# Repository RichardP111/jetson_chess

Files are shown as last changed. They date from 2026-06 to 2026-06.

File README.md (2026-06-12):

# ♟️ Jetson Smart Chess Board

<p align="center">
  <strong>AI-powered smart chess board running entirely on a Jetson Orin Nano</strong>
</p>

<p align="center">
  
  
  
  
</p>

---

## 🚀 Overview

A fully self-contained smart chess board powered by the **NVIDIA Jetson Orin Nano**.

- ♟️ Three game modes: AI (Stockfish), Online (Lichess), Local 2-Player
- 🎯 Pawn promotion selector (Q R B N) via coloured LED quadrants
- ↩️ Undo last move (button combo or web dashboard)
- 📊 Eval bar on OLED and web dashboard
- 🔊 Voice announcements — auto-enabled when a USB speaker is connected
- 💾 USB game save — auto-saves PGN if a USB drive is plugged in
- 🧠 Post-game blunder analysis (top-3 mistakes highlighted)
- 🌐 Web dashboard with move input, custom LED theme builder, PGN download, OTA update
- ⚡ Fast startup (~1 second instead of 64)
- 🧩 Central `config.py` — no more scattered magic numbers

---

## ✨ Features

### Game Modes
| Button | Mode | Description |
|---|---|---|
| 1 | vs AI | Stockfish on-device, configurable difficulty 1-20 |
| 2 | Online | Lichess board API (requires token) |
| 3 | Local 2P | Pass-and-play, no network needed |

### Controls
| Action | Input |
|---|---|
| Hint | Press HINT button |
| Undo last move | Hold Btn 8 + press HINT |
| New game | Hold OK + press HINT |
| Promotion choice | Buttons 1-4 when pawn reaches back rank |

### Visual Feedback
| Event | LED |
|---|-----|
| Move | Fading trail animation |
| Hint | Cyan trail + squares |
| Capture | Red flash × 3 |
| Check | Red pulse from king |
| Promotion Q | White flash |
| Promotion R | Red flash |
| Promotion B | Blue flash |
| Promotion N | Yellow flash |
| Undo | Orange right-to-left wipe |
| Checkmate | Rainbow victory sweep |

---

## 🔧 Hardware

| Component | Description |
|---|---|
| Jetson Orin Nano 8GB | Main compute platform |
| WS2812B LEDs (64 + 22) | Chessboard + control panel |
| Push buttons (×10) | Input system |
| TXS0108E | Logic level shifter |
| SSD1306 OLED (128×64) | Status display |
| USB speaker (optional) | Voice announcements |
| USB drive (optional) | Game save as PGN |

### GPIO Mapping (Jetson 40-pin Header)
| Function | Pin |
|---|-----|
| Chessboard LED Data | 32 |
| Control Panel LED Data | 33 |
| Buttons 1-9 | 7, 11, 13, 15, 29, 31, 26, 24, 19 |
| HINT button | 16 |

---

## 🖥️ Software Setup

### 1. Install system packages
```bash
sudo apt update
sudo apt install python3-pip stockfish espeak-ng -y
```

### 2. Install Python packages
```bash
pip install -r requirements.txt --break-system-packages
```

### 3. Setup GPIO permissions
```bash
sudo groupadd -f gpio
sudo usermod -aG gpio $USER
sudo cp /opt/nvidia/jetson-gpio/etc/99-gpio.rules /etc/udev/rules.d/
sudo udevadm control --reload-rules && sudo udevadm trigger
```

### 4. LED permissions
```bash
sudo cp scripts/99-ws281x.rules /etc/udev/rules.d/
sudo udevadm control --reload-rules
```

### 5. Configure .env
```bash
cp .env.example .env
# Edit .env and fill in FLASK_SECRET_KEY (required)
# Add LICHESS_TOKEN if using online play
# Add OTA_TOKEN to enable web dashboard updates
```

Generate a secret key:
```bash
python3 -c "import secrets; print(secrets.token_hex(32))"
```

---

## ▶️ Running

### Development (no hardware)
```bash
MOCK_LEDS=1 MOCK_BUTTONS=1 MOCK_OLED=1 MOCK_VOICE=1 MOCK_ONLINE=1 \
  python3 -m pytest tests/test_mock_game.py -v
```

### Hardware test
```bash
sudo python3 tests/test_leds_buttons.py
```

### Stockfish test
```bash
python3 tests/test_stockfish.py
```

### Full system
```bash
sudo python3 main.py
```

### Auto-start on boot
```bash
sudo cp scripts/chess.service /etc/systemd/system/
sudo systemctl daemon-reload
sudo systemctl enable chess.service
sudo systemctl start chess.service
```

---

## 🌐 Web Dashboard

Access at `http://<jetson-ip>:5000` from any device on the same network.

Features:
- Live board with move arrows and eval bar
- Enter moves directly from browser (UCI notation, e.g. `e2e4`)
- Request hints and undo
- New game
- LED theme selector + custom colour picker
- Save game to USB / download PGN
- Voice toggle
- Jetson system stats (CPU temp, load, RAM)
- OTA git-pull + restart (requires `OTA_TOKEN` in `.env`)

---

## 🔊 Voice Announcements

Voice is automatically enabled when a USB speaker is detected. No configuration needed — just plug one in. If no speaker is present, the feature is silently disabled.

Install the TTS engine (if not already via apt):
```bash
sudo apt install espeak-ng -y
# OR
pip install pyttsx3 --break-system-packages
```

To permanently disable voice even with a speaker: set `DISABLE_VOICE=1` in `.env`.

---

## 💾 USB Game Save

If a USB drive is plugged in, games are automatically saved as PGN files after each game ends. Files are stored in a `chess_games/` folder on the drive. You can also trigger a manual save via the web dashboard.

No USB drive? No problem — the feature is silently skipped.

---

## 📁 Project Structure

```
jetson_chess/
├── main.py              
├── config.py            
├── voice.py             
├── usb_storage.py       
├── hardware/
│   ├── leds.py
│   └── buttons.py
├── chess_engine/
│   ├── board_state.py
│   └── stockfish.py
├── online/
│   └── lichess.py
├── ui/
│   ├── display.py
│   └── animations.py
├── oled/
│   └── oled_display.py
├── web/
│   └── server.py
├── tests/
│   ├── test_mock_game.py
│   ├── test_leds_buttons.py
│   └── test_stockfish.py
└── scripts/
    ├── chess.service
    └── 99-ws281x.rules
```

---

## ⚖️ License & Acknowledgements

- **Software:** MIT License
- **Hardware (3D models):** CC BY-NC-SA 4.0

Hardware models are a derivative of the original Smart Chess project by DIYMachines (CC BY-NC-SA 4.0). Modifications: Jetson electronics bay, airflow cutouts for Jetson fan, repositioned OLED mount, updated button panel layout.

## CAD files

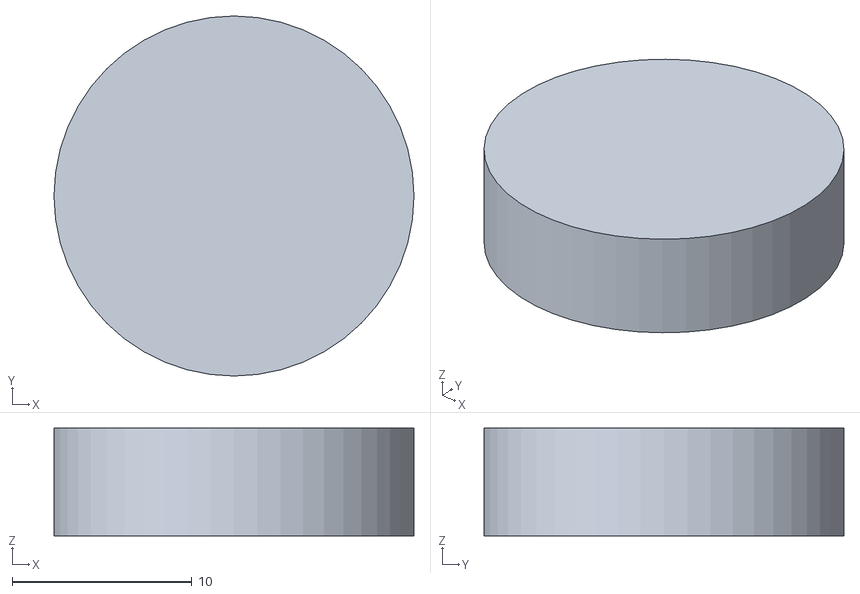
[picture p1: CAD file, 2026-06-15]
3D models/Base/Chessboard - Feet.stl
20.0 x 20.0 x 6.00

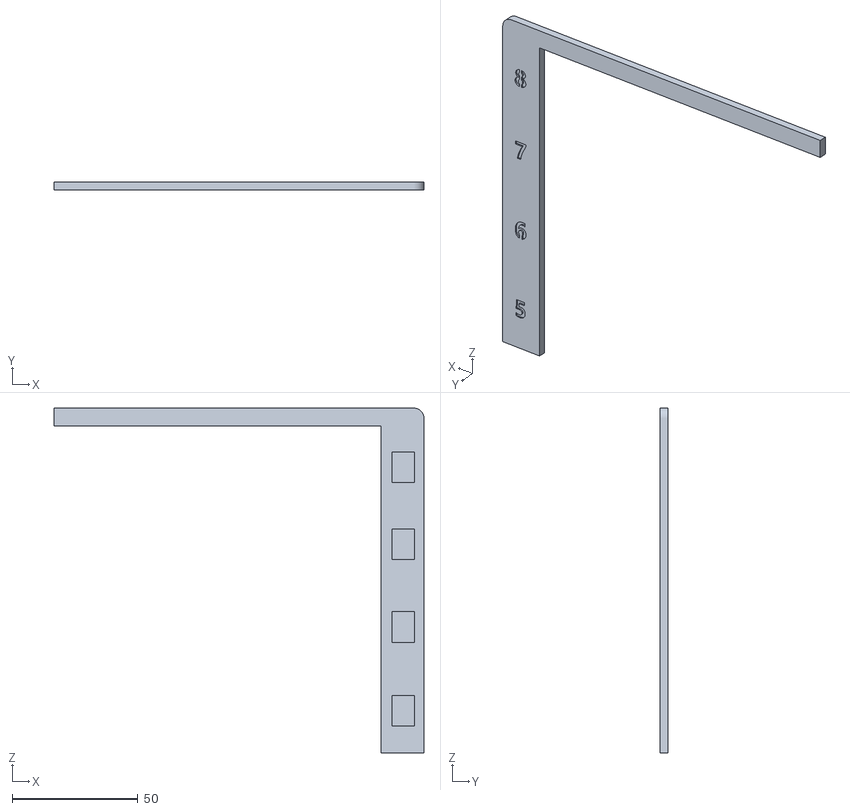
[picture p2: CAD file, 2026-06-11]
3D models/Labels/Chessboard - Label 1-4.STL
147.0 x 3.00 x 136.9

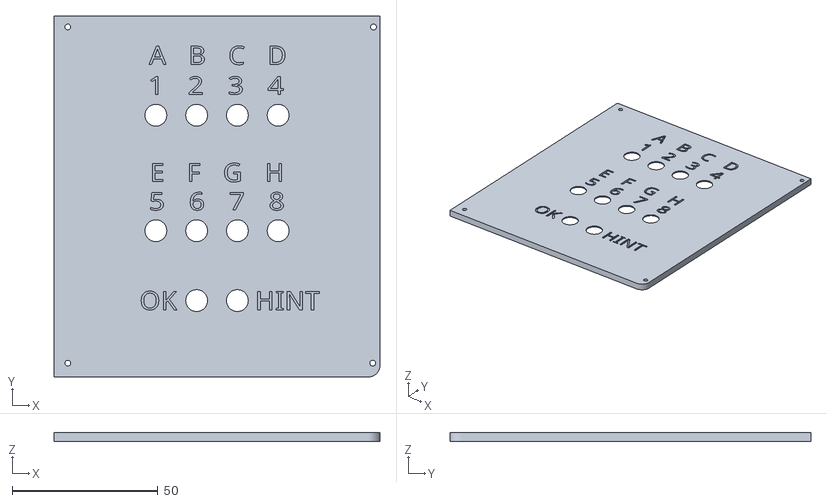
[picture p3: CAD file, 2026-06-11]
3D models/Panels/Chessboard - Button Panel.stl
112.0 x 124.0 x 3.00

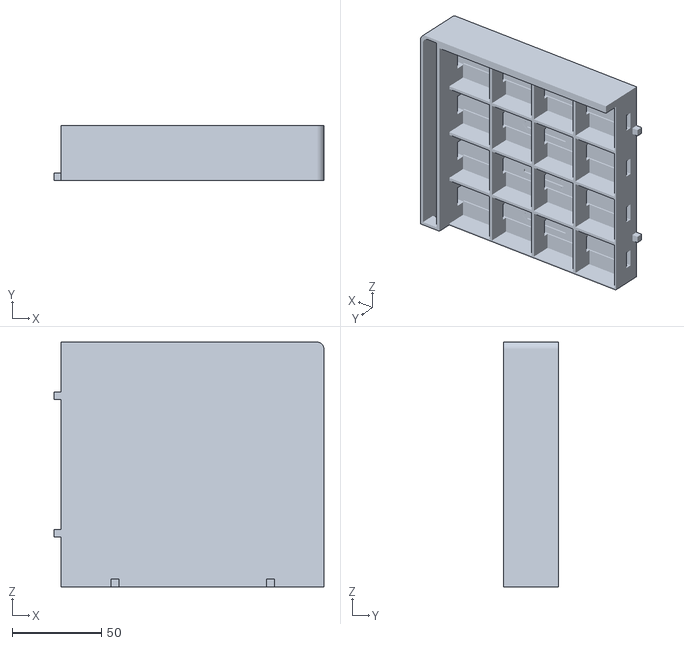
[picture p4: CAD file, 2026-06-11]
3D models/Base/Chessboard - Top Lights.STL
151.0 x 31.0 x 136.9

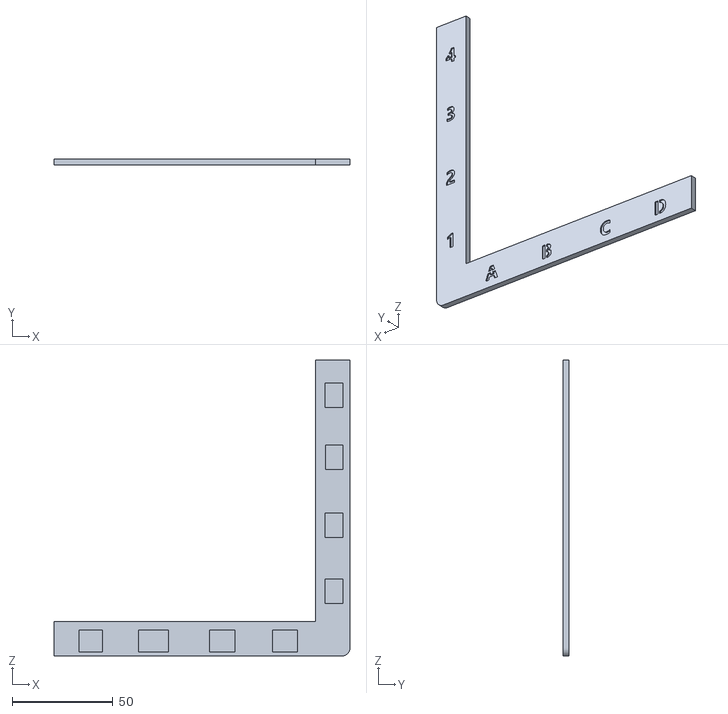
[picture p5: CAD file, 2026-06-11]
3D models/Labels/Chessboard - Label A1-D4.STL
147.0 x 3.00 x 147.0

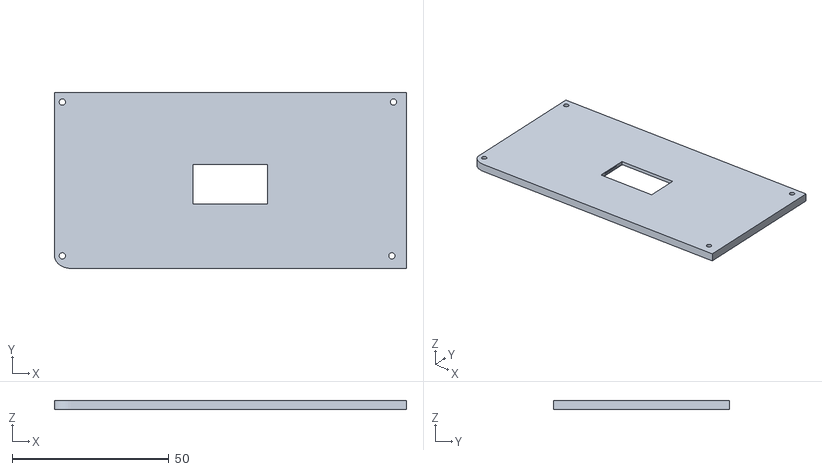
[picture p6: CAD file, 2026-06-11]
3D models/Panels/Chessboard - Screen Panel.stl
112.1 x 56.0 x 3.00

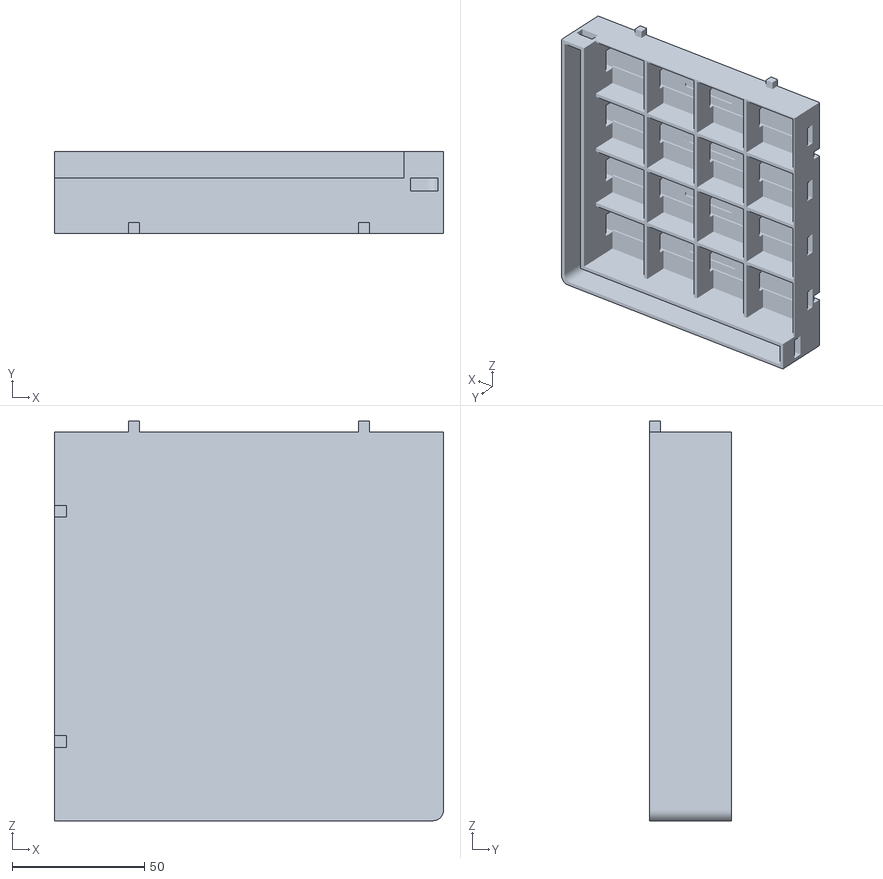
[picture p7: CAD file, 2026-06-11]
3D models/Base/Chessboard - Bottom Lights.STL
147.0 x 31.0 x 150.9

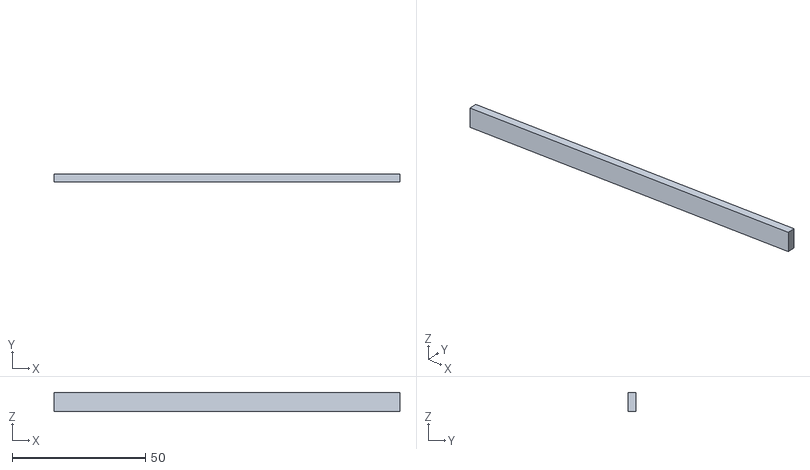
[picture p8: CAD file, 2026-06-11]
3D models/Labels/Chessboard - Blank.STL
129.8 x 3.00 x 7.15

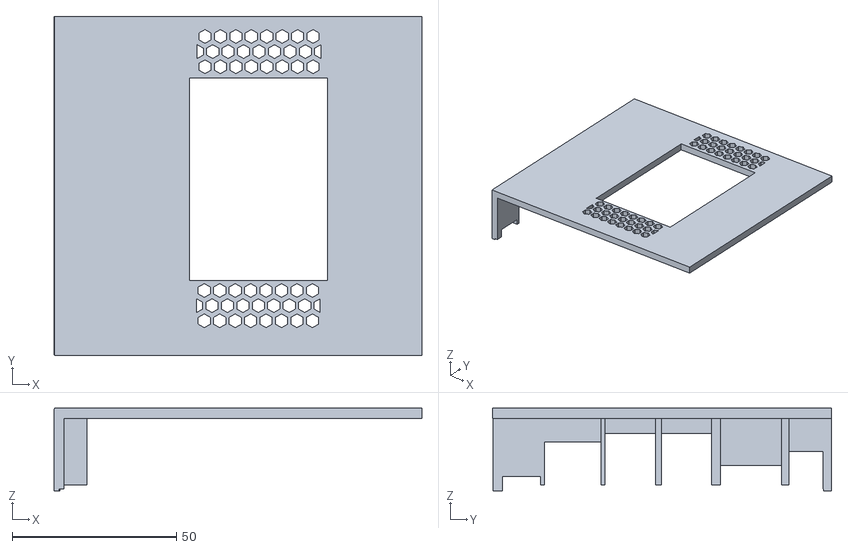
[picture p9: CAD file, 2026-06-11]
3D models/Panels/Chessboard - Middle Jetson Panel.stl
112.0 x 103.2 x 25.2

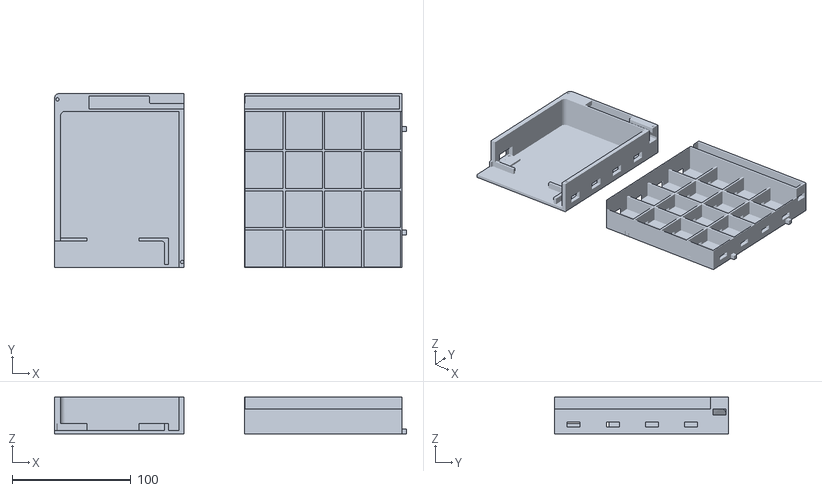
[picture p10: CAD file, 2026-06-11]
3D models/Base/Chessboard - Bottom Elec Split.stl
296.6 x 146.6 x 31.0

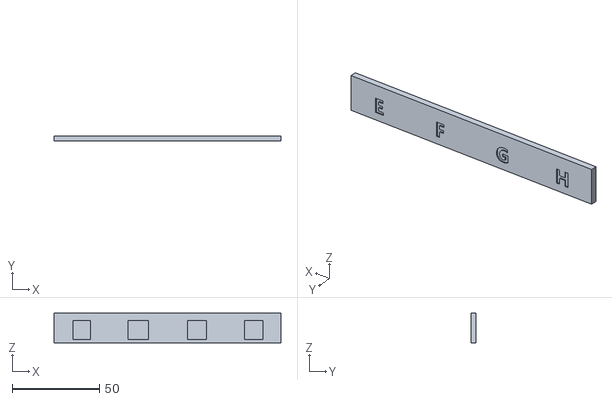
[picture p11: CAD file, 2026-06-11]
3D models/Labels/Chessboard - Label 5-8.STL.STL
129.8 x 3.00 x 17.0

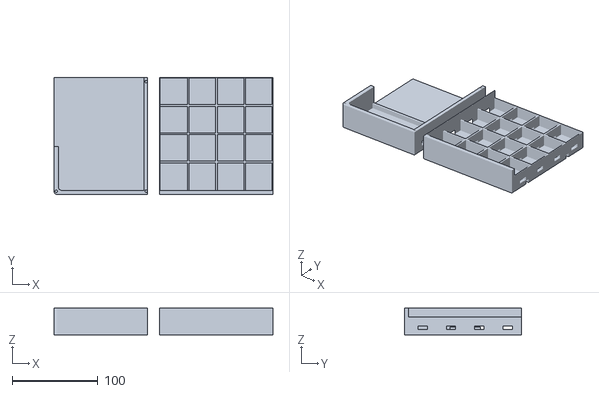
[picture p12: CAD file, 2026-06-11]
3D models/Base/Chessboard - Top Elec Split.stl
255.7 x 136.9 x 31.0

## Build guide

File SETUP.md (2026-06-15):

# Jetson Smart Chess Board — Full Setup Guide

Run these commands **in order** on the Jetson Orin Nano (JetPack 6).
Everything assumes you are in the project root: `cd ~/jetson_chess`

---

## 1. System packages

```bash
sudo apt update && sudo apt upgrade -y

sudo apt install -y \
    python3-pip \
    stockfish \
    espeak-ng \
    ntfs-3g \
    exfatprogs \
    i2c-tools \
    git
```

> **exFAT note:** if `exfatprogs` isn't found try `exfat-fuse` instead.

---

## 2. Python packages

```bash
pip install -r requirements.txt --break-system-packages
```

If `rpi_ws281x` fails (it's Raspberry Pi only — the Jetson uses SPI directly
via `spidev`):

```bash
pip install -r requirements.txt --break-system-packages --ignore-requires-python
# or just skip rpi_ws281x — it's not used at runtime, only spidev is
pip install spidev --break-system-packages
```

---

## 3. Environment file

```bash
cp .env.example .env   # or create it fresh:
nano .env
```

Minimum required:

```
FLASK_SECRET_KEY=<generate one — see below>
LICHESS_TOKEN=        # optional, only needed for online mode
OTA_TOKEN=            # optional, enables web dashboard git-pull updates
DISABLE_VOICE=0       # set to 1 to always silence TTS
```

Generate a secret key:

```bash
python3 -c "import secrets; print(secrets.token_hex(32))"
```

---

## 4. GPIO permissions

```bash
sudo groupadd -f gpio
sudo usermod -aG gpio $USER

# Jetson GPIO udev rule (comes with JetPack, just link it)
sudo cp /opt/nvidia/jetson-gpio/etc/99-gpio.rules /etc/udev/rules.d/ 2>/dev/null || true
sudo udevadm control --reload-rules && sudo udevadm trigger
```

---

## 5. LED (SPI) permissions

```bash
sudo cp scripts/99-ws281x.rules /etc/udev/rules.d/
sudo udevadm control --reload-rules && sudo udevadm trigger
```

The chess LEDs use SPI1 MOSI (BOARD pin 19) via `/dev/spidev0.0`.
Make sure SPI is enabled in the Jetson pin-mux / `jetson-io` tool if it
isn't already.

---

## 6. USB hotplug (plug-and-play USB drives)

```bash
# Mount script
sudo cp scripts/chess-usb-mount.sh /usr/local/bin/
sudo chmod +x /usr/local/bin/chess-usb-mount.sh

# udev rule
sudo cp scripts/99-chess-usb.rules /etc/udev/rules.d/
sudo udevadm control --reload-rules && sudo udevadm trigger

# Fixed mount point
sudo mkdir -p /mnt/usb
```

After this, plugging in any FAT32/exFAT/NTFS USB drive will auto-mount
it at `/mnt/usb` within about a second. Unplugging safely unmounts it.

Check the mount log any time:

```bash
cat /tmp/chess-usb.log
```

---

## 7. OLED I2C

The SSD1306 OLED uses I2C bus 7 (BOARD pins 3/5) by default.
Confirm it's visible:

```bash
sudo i2cdetect -y 7
# Should show 3c at address 0x3C
```

If it's on a different bus, set in `.env`:

```
OLED_I2C_PORT=1
OLED_I2C_ADDR=0x3C
```

---

## 8. Auto-start on boot (systemd)

```bash
sudo cp scripts/chess.service /etc/systemd/system/
sudo systemctl daemon-reload
sudo systemctl enable chess.service
sudo systemctl start chess.service
```

Check it's running:

```bash
sudo systemctl status chess.service
sudo journalctl -u chess.service -f   # live logs
```

---

## 9. Test everything works

```bash
# Test Stockfish
python3 tests/test_stockfish.py

# Test LEDs + buttons (needs physical hardware)
sudo python3 tests/test_leds_buttons.py

# Full mock run (no hardware needed — keyboard simulates buttons)
MOCK_LEDS=1 MOCK_BUTTONS=1 MOCK_OLED=1 MOCK_VOICE=1 MOCK_ONLINE=1 \
    python3 main.py
```

---

## 10. Web dashboard

Once running, open a browser on any device on the same network:

```
http://<jetson-ip>:5000
```

Find the Jetson's IP:

```bash
hostname -I
```

Or it shows on the OLED at startup.

---

## All-in-one first-time setup (copy/paste)

```bash
# Run from the project root as your normal user
set -e

# 1. System packages
sudo apt update
sudo apt install -y python3-pip stockfish espeak-ng ntfs-3g exfatprogs i2c-tools git

# 2. Python packages
pip install -r requirements.txt --break-system-packages

# 3. .env
if [ ! -f .env ]; then
    echo "FLASK_SECRET_KEY=$(python3 -c 'import secrets; print(secrets.token_hex(32))')" > .env
    echo "LICHESS_TOKEN=" >> .env
    echo "OTA_TOKEN=" >> .env
    echo "DISABLE_VOICE=0" >> .env
    echo "Created .env — edit it to add LICHESS_TOKEN if you want online play"
fi

# 4. GPIO
sudo groupadd -f gpio
sudo usermod -aG gpio $USER
sudo cp /opt/nvidia/jetson-gpio/etc/99-gpio.rules /etc/udev/rules.d/ 2>/dev/null || true

# 5. LEDs
sudo cp scripts/99-ws281x.rules /etc/udev/rules.d/

# 6. USB hotplug
sudo cp scripts/chess-usb-mount.sh /usr/local/bin/
sudo chmod +x /usr/local/bin/chess-usb-mount.sh
sudo cp scripts/99-chess-usb.rules /etc/udev/rules.d/
sudo mkdir -p /mnt/usb

# Reload udev
sudo udevadm control --reload-rules && sudo udevadm trigger

# 7. Systemd service
sudo cp scripts/chess.service /etc/systemd/system/
sudo systemctl daemon-reload
sudo systemctl enable chess.service

echo ""
echo "✅ Setup complete. Start with:"
echo "   sudo systemctl start chess.service"
echo "   sudo journalctl -u chess.service -f"
```

---

## Troubleshooting

| Problem | Check |
|---|---|
| LEDs not working | `ls /dev/spidev*` — SPI must be enabled in jetson-io |
| OLED blank | `sudo i2cdetect -y 7` — confirm address 0x3C |
| Buttons not responding | `groups` — must include `gpio`; log out and back in |
| USB not detected | `cat /tmp/chess-usb.log` — check mount script output |
| Web dashboard won't load | `sudo journalctl -u chess.service -f` — check for port 5000 errors |
| Lichess not connecting | Check `LICHESS_TOKEN` in `.env` is a valid board token |
| Voice silent | `aplay -l` — confirm USB speaker shows as a card |

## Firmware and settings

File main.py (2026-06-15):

#!/usr/bin/env python3
# =============================================================================
# main.py
# Author : Richard Pu
# Created: 2026-06-10  |  Revised: 2026-06-12
# Purpose: Core orchestrator for the Jetson Orin Nano Smart Chess Board.
# =============================================================================

from __future__ import annotations

import os
import sys
import time
import signal
import logging
import threading
import logging.handlers
from typing import Any, Optional

import chess as _chess
from dotenv import load_dotenv

from config import CFG
from hardware.leds import LEDController
from hardware.buttons import ButtonController, MATRIX_MAP, HINT_POS
from chess_engine.board_state import BoardState
from chess_engine.stockfish import StockfishEngine
from online.lichess import LichessClient
from ui.display import Display
from ui.animations import AnimationEngine
from oled.oled_display import OLEDDisplay
from voice import voice
from storage import usb
import web.server as web_server

logging.basicConfig(
    level=logging.INFO,
    format="%(asctime)s [%(levelname)s] %(name)s: %(message)s",
    handlers=[
        logging.StreamHandler(sys.stdout),
        logging.handlers.RotatingFileHandler(
            "/tmp/chess.log", maxBytes=1_000_000, backupCount=3
        ),
    ],
)

log = logging.getLogger("main")

PROMOTION_MAP = {1: "q", 2: "r", 3: "b", 4: "n"}
PROMOTION_NAME = {"q": "queen", "r": "rook", "b": "bishop", "n": "knight"}


class ChessGame:
    def __init__(self):
        log.info("Initialising Jetson Smart Chess Board v3...")
        load_dotenv()

        self.buttons   = ButtonController()
        self.leds      = LEDController()
        self.board     = BoardState()
        self.display   = Display(self.leds, self.board, self.buttons)
        self.anim      = AnimationEngine(self.leds, self.board)
        self.oled      = OLEDDisplay()
        self.stockfish = StockfishEngine()
        self.lichess   = LichessClient()

        self.game_mode           = None
        self.colour_choice       = None
        self.difficulty          = CFG.difficulty_default
        self.move_timeout_ms     = CFG.movetime_default_ms
        self.suggested_best_move = ""
        self._voice_enabled      = voice.available

        self._clock = {"White": 0.0, "Black": 0.0}
        self._clock_start: Optional[float] = None
        self._active_colour: str = "White"

        self._new_game_requested = threading.Event()
        self._web_move_queue: list = []
        self._web_move_event  = threading.Event()
        self._web_ok_event = threading.Event()
        self._last_move_was_web = False

        self._web_setup_answer = None
        self._web_setup_event  = threading.Event()
        self._setup_preview_val: int = 0   

        self._web_mode_queue: list = []
        self._web_mode_event  = threading.Event()

        self._web_player: Optional[str] = None

        self._hint_count = 0
        self._last_hint_time_disco = 0.0

        web_server.register_callbacks(
            new_game           = self._new_game_sequence,
            hint               = lambda: self._hint_isr(None),
            set_theme          = self.anim.set_theme,
            move_input         = self._web_move_received,
            undo               = self._undo_sequence,
            save_usb           = self._save_to_usb,
            toggle_voice       = self._toggle_voice,
            web_mode_select    = self._web_mode_received,
            web_setup_answer   = self._web_setup_received,
            slider_preview     = self._slider_preview,
            disco              = self._disco_mode,
            web_ok             = self._web_ok_received,
            load_usb_game      = self._load_game_from_usb,
            set_brightness     = self._set_brightness_live,
            viewer_board_reset = self._viewer_board_reset,
            viewer_board_goto  = self._viewer_board_goto,
            evaluate_fen       = lambda fen: self.stockfish.evaluate(fen, depth=10),
        )
        web_server.start_server()
        web_server.update_state(voice_enabled=self._voice_enabled)

        signal.signal(signal.SIGINT,  self._shutdown)
        signal.signal(signal.SIGTERM, self._shutdown)
        self.buttons.register_hint_callback(self._hint_isr)

        # ── Background USB hot-plug monitor ──────────────────────────────────
        def _usb_monitor():
            prev = None
            while True:
                cur = usb.is_available()
                if cur != prev:
                    prev = cur
                    games = usb.list_saved_games() if cur else []
                    # Single emission — both flags land in the same socket push
                    web_server.update_state(usb_available=cur, usb_games=games)
                    log.info(f"USB drive {'connected' if cur else 'disconnected'} — {len(games)} game(s)")
                # Recheck for USB speaker plugged in after boot
                if not voice.available:
                    if voice.recheck_audio():
                        self._voice_enabled = True
                        web_server.update_state(voice_enabled=True)
                        log.info("USB speaker detected — voice enabled")
                time.sleep(2.0)   # 2s instead of 3s for snappier detection

        # Run one check immediately so dashboard is correct on first connect
        _initial_usb = usb.is_available()
        web_server.update_state(
            usb_available=_initial_usb,
            usb_games=usb.list_saved_games() if _initial_usb else [],
        )
        threading.Thread(target=_usb_monitor, daemon=True, name="usb-monitor").start()

    def run(self):
        self.oled.show_loading(0, 64)
        
        self.display.show_opening_markings()
        self.anim.rain_effect(duration=2.0)

        self._startup_sequence()
        while True:
            self._new_game_requested.clear()
            try:
                self._game_loop()
            except _NewGameException:
                log.info("New game requested lifecycle event")
                self._new_game_sequence()
            except KeyboardInterrupt:
                self._shutdown()

    def _startup_sequence(self):
        for i in range(64):
            row = i // 8
            col = i % 8
            self.leds.chess_set_pixel(col, row, (0, 255, 0))
            self.leds.chess_show()
            self.oled.show_loading(i + 1, 64)
            time.sleep(CFG.startup_led_delay_s)

        ip = self._get_local_ip()
        if ip:
            self.oled.show_network_info(ip)
        else:
            self.oled.show_status("No network — offline mode")
        time.sleep(2.0)
        self._choose_game_mode()
        self._setup_game()
        self.anim.show_board_themed()
        self.oled.show_game(self._current_turn(), status="Game ready!")
        web_server.update_state(game_active=True, status="Game started", usb_available=usb.is_available())

    def _game_loop(self):
        while True:
            if self._new_game_requested.is_set():
                raise _NewGameException()

            current = self._current_turn()
            self.oled.show_game(current, status="Your move...")
            web_server.update_state(whose_turn=current, status="Your move", usb_available=usb.is_available())

            if voice.available and self._voice_enabled:
                voice.announce_status(f"{current}'s turn")

            self._start_clock(current)
            humans_move = self._humans_go()
            self._stop_clock(current)
            log.info(f"Human move entered: {humans_move}")

            if self.board.is_promotion(humans_move):
                humans_move = self._ask_promotion(humans_move)

            # ── FIX: FORCE LED FEEDBACK FOR ALL MOVES (PHYSICAL & WEB) ──
            # This ensures web dashboard inputs physically light up the physical board matrix squares
            from_sq = humans_move[:2]
            to_sq = humans_move[2:4]
            
            # Clear previous highlights, paint the fading move trail animation, and mark destination
            self.anim.show_board_themed()
            self.anim.move_trail(from_sq, to_sq)
            self.display.light_up_move(humans_move, mode="Y")

            legal = self._check_move_legal(humans_move)
            if not legal:
                log.warning("Illegal move processed")
                self.display.error_animation()
                self.anim.show_board_themed()
                self.oled.show_status("Illegal move — try again")
                if self._voice_enabled:
                    voice.announce_status("Illegal move, try again")
                continue

            captured = self.board.is_capture(humans_move)
            self.board.apply_move(humans_move)
            self._push_move_to_ui(humans_move, "Human")

            cb = _chess.Board(self.board.fen())
            is_check     = cb.is_check()
            is_checkmate = cb.is_checkmate()

            if is_checkmate:
                self._end_game("Human")
                return
            elif cb.is_stalemate():
                self._end_game_draw("Stalemate")
                return
            elif cb.is_insufficient_material():
                self._end_game_draw("Insufficient material")
                return
            elif cb.is_seventyfive_moves():
                self._end_game_draw("75-move rule")
                return
            elif is_check:
                king_sq = cb.king(cb.turn)
                if king_sq is not None:
                    self.anim.check_alert(king_sq % 8, 7 - (king_sq // 8))
                self.oled.show_status("CHECK!")
                web_server.update_state(status="CHECK!")
                if self._voice_enabled:
                    voice.announce_status("Check!")

            if self._voice_enabled:
                voice.announce_move(humans_move, captured=captured,
                                    is_check=is_check and not is_checkmate,
                                    is_checkmate=is_checkmate)

            self.anim.show_board_themed()

            if self.game_mode == "Stockfish":
                self._stockfish_turn()
            elif self.game_mode == "OnlineHuman":
                self._online_turn(humans_move)
            elif self.game_mode == "LocalHuman":
                next_turn = self._current_turn()
                self.oled.show_pass_board(next_turn, self.board.move_count())
                if self._voice_enabled:
                    voice.announce_status(f"Pass the board to {next_turn}")
                time.sleep(3.0)

            self.anim.show_board_themed()
            self.oled.show_game(
                self._current_turn(),
                last_move=self.board._move_history_uci()[-1] if self.board._move_history_uci() else "",
                move_history=self.board._move_history_uci(),
                eval_score=self.stockfish.evaluate(self.board.fen()),
            )

    def _stockfish_turn(self):
        self.oled.show_status("Engine thinking...")
        web_server.update_state(thinking=True, status="Engine thinking...")
        self.anim.start_thinking_animation()

        engine_move, best_hint = self.stockfish.get_move(
            self.board.fen(),
            skill_level=self.difficulty,
            movetime_ms=self.move_timeout_ms,
        )
        self.anim.stop_thinking_animation()
        web_server.update_state(thinking=False)
        self.suggested_best_move = best_hint

        eval_score = self.stockfish.evaluate(self.board.fen())
        web_server.update_state(eval_score=eval_score)

        if not engine_move:
            cb = _chess.Board(self.board.fen())
            if cb.is_checkmate():
                self._end_game("Human")
            else:
                self._end_game_draw("Engine resigned or terminated")
            return

        captured_by_engine = self.board.is_capture(engine_move)
        self.anim.move_trail(engine_move[:2], engine_move[2:4])
        self.display.light_up_move(engine_move, mode="N")
        log.info(f"Engine move: {engine_move}")

        self.board.apply_move(engine_move)

        cb_after = _chess.Board(self.board.fen())
        is_check = cb_after.is_check()
        is_checkmate = cb_after.is_checkmate()

        if self._voice_enabled:
            voice.announce_move(engine_move, captured=captured_by_engine,
                                is_check=is_check and not is_checkmate,
                                is_checkmate=is_checkmate)

        if is_checkmate:
            self._push_move_to_ui(engine_move, "Computer")
            self._end_game("Computer")
            return

        # ── Push move data to UI (no needs_ok here — sent separately below) ──
        ok_status = f"AI played {engine_move.upper()}"
        if is_check:
            ok_status = f"CHECK! AI played {engine_move.upper()}"
        history    = self.board._move_history_uci()
        whose      = self._current_turn()
        eval_score = self.stockfish.evaluate(self.board.fen())
        self.oled.push_move(engine_move, whose, eval_score=eval_score)
        web_server.update_state(
            fen=self.board.fen(), move_history=history, whose_turn=whose,
            last_move=engine_move, status=ok_status, eval_score=eval_score,
        )

        if is_check:
            king_sq = cb_after.king(cb_after.turn)
            if king_sq is not None:
                self.anim.check_alert(king_sq % 8, 7 - (king_sq // 8))
            self.oled.show_status("CHECK!")

        # ── CONFIRMATION: show OK banner via dedicated direct emit (no race) ──
        self.oled.show_game(
            "Human",
            last_move=engine_move,
            move_history=history,
            status=f"AI: {engine_move.upper()} — OK to continue"
        )
        self.leds.control_panel_set_pixel(4, (255, 255, 255))
        self.leds.panel_show()
        web_server.show_ok_banner(engine_move.upper())

        # Clear stale events before waiting
        self._web_ok_event.clear()
        while self.buttons.detect_button_nowait() != 0:
            pass

        while True:
            if self._new_game_requested.is_set():
                web_server.hide_ok_banner()
                raise _NewGameException()
            if self._web_ok_event.is_set():
                self._web_ok_event.clear()
                break
            if self._web_move_event.is_set():
                break
            btn = self.buttons.detect_button_nowait()
            if btn == 9:
                break
            time.sleep(0.002)

        web_server.hide_ok_banner()
        self.leds.control_panel_fill((0, 0, 0), start=0, count=6)
        self.leds.panel_show()
        self._last_move_was_web = False

    def _online_turn(self, humans_move: str):
        try:
            self.lichess.send_move(humans_move)
        except Exception as e:
            log.error(f"Lichess send_move failed: {e}")
        self.oled.show_status("Waiting for opponent...")
        web_server.update_state(status="Waiting for opponent...")
        opponent_move = self.lichess.wait_for_move()
        if not opponent_move or len(opponent_move) < 4:
            log.error(f"Invalid opponent move received: {opponent_move!r} — likely network loss")
            self.oled.show_status("Connection lost — ending game")
            web_server.update_state(status="Network lost — game ended")
            time.sleep(3.0)
            raise _NewGameException()
        log.info(f"Online opponent move: {opponent_move}")
        captured = self.board.is_capture(opponent_move)
        self.anim.move_trail(opponent_move[:2], opponent_move[2:4])
        self.display.light_up_move(opponent_move, mode="N")
        self.board.apply_move(opponent_move)
        if self._voice_enabled:
            voice.announce_move(opponent_move, captured=captured)

        # ── Push move data to UI then immediately show OK banner ──
        ok_status = f"Opponent played {opponent_move.upper()}"
        history    = self.board._move_history_uci()
        whose      = self._current_turn()
        eval_score = self.stockfish.evaluate(self.board.fen())
        self.oled.push_move(opponent_move, whose, eval_score=eval_score)
        web_server.update_state(
            fen=self.board.fen(), move_history=history, whose_turn=whose,
            last_move=opponent_move, status=ok_status, eval_score=eval_score,
        )

        # ── CONFIRMATION: physical OK or web OK both accepted ──
        current_human_turn = "White" if self.colour_choice == "white" else "Black"
        self.oled.show_game(
            current_human_turn,
            last_move=opponent_move,
            move_history=history,
            status=f"Net: {opponent_move.upper()} — OK to continue"
        )
        self.leds.control_panel_set_pixel(4, (255, 255, 255))
        self.leds.panel_show()
        web_server.show_ok_banner(opponent_move.upper())

        self._web_ok_event.clear()
        while self.buttons.detect_button_nowait() != 0:
            pass

        while True:
            if self._new_game_requested.is_set():
                web_server.hide_ok_banner()
                raise _NewGameException()
            if self._web_ok_event.is_set():
                self._web_ok_event.clear()
                break
            if self._web_move_event.is_set():
                break
            btn = self.buttons.detect_button_nowait()
            if btn == 9:
                break
            time.sleep(0.002)

        web_server.hide_ok_banner()
        self.leds.control_panel_fill((0, 0, 0), start=0, count=6)
        self.leds.panel_show()
        self._last_move_was_web = False  # Reset for next human turn

    def _choose_game_mode(self):
        log.info("Waiting for game mode selection...")
        self.oled.show_mode_select()
        self.leds.control_panel_fill((255, 255, 255), start=0, count=5)
        self.leds.panel_show()
        web_server.update_state(setup_phase="mode_select")

        if self._voice_enabled:
            threading.Thread(
                target=voice.announce_status,
                args=("Select game mode. Press 1 for AI, 2 for Lichess, 3 for local two player.",),
                daemon=True
            ).start()

        # Flush any lingering button events
        while self.buttons.detect_button_nowait() != 0:
            pass

        last_activity = time.time()
        is_asleep = False

        while True:
            # Check for physical matrix actions
            btn = self.buttons.detect_button_nowait()
            
            # Check for remote web interface actions
            web_triggered = False
            if self._web_mode_event.is_set():
                self._web_mode_event.clear()
                if self._web_mode_queue:
                    web_triggered = True

            # If any interaction occurs, process wake rules or selection inputs
            if btn != 0 or web_triggered:
                last_activity = time.time()
                
                if is_asleep:
                    print("[SYSTEM] Board activity detected. Waking up from sleep mode.")
                    is_asleep = False
                    self.anim.stop_sleep_animation()
                    
                    # Restore the interactive menu assets
                    self.oled.show_mode_select()
                    self.leds.control_panel_fill((255, 255, 255), start=0, count=5)
                    self.leds.panel_show()
                    
                    # Consume the physical button press used to wake the board
                    btn = 0 
                    
                    if web_triggered:
                        self._apply_web_mode(self._web_mode_queue.pop(0))
                        break
                    continue
                else:
                    # Standard selection logic when awake
                    if btn in (1, 2, 3):
                        break
                    if web_triggered:
                        self._apply_web_mode(self._web_mode_queue.pop(0))
                        break

            # Inactivity timeout condition check
            if not is_asleep and (time.time() - last_activity > CFG.menu_sleep_timeout_s):
                print(f"[SYSTEM] Inactivity timeout ({CFG.menu_sleep_timeout_s}s) reached. Entering sleep mode.")
                is_asleep = True
                self.oled.show_menu_sleep()
                self.anim.start_sleep_animation()

            time.sleep(0.002)  # Maintain stable 500Hz cycle check speed

        # Handle game mode configuration assignment once selection is confirmed
        if btn == 1:
            self.game_mode = "Stockfish"
            self._web_player = None
            self.display.confirm_ai_mode()
        elif btn == 2:
            self.game_mode = "OnlineHuman"
            self._web_player = None
            self.display.confirm_online_mode()
        elif btn == 3:
            self.game_mode = "LocalHuman"
            self._web_player = None
            self.display.confirm_local_mode()

        web_server.update_state(game_mode=self.game_mode, setup_phase="idle", web_player=self._web_player)

    def _apply_web_mode(self, web_mode: str):
        if web_mode == "stockfish":
            self.game_mode = "Stockfish"
            self._web_player = None
        elif web_mode == "lichess":
            self.game_mode = "OnlineHuman"
            self._web_player = None
        elif web_mode == "local":
            self.game_mode = "LocalHuman"
            self._web_player = None
        elif web_mode == "web_vs_ai":
            self.game_mode = "Stockfish"
            self._web_player = "White"
        elif web_mode == "web_local":
            self.game_mode = "LocalHuman"
            self._web_player = "both"

    def _setup_game(self):
        self.leds.control_panel_fill((255, 255, 255), start=0, count=4)
        self.leds.panel_show()
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

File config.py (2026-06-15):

# =============================================================================
# config.py
# Author : Richard Pu
# Created: 2026-06-12
# Purpose: Central configuration dataclass for the Jetson Smart Chess Board.
# =============================================================================

import os
from dataclasses import dataclass, field


@dataclass
class GameConfig:
    # ── Stockfish ─────────────────────────────────────────────────────────────
    stockfish_path: str      = field(default_factory=lambda: os.environ.get("STOCKFISH_PATH", "/usr/games/stockfish"))
    difficulty_min: int      = 1
    difficulty_max: int      = 20
    difficulty_default: int  = 10
    movetime_min_ms: int     = 3_000
    movetime_max_ms: int     = 12_000
    movetime_default_ms: int = 5_000

    # ── LED hardware ──────────────────────────────────────────────────────────
    chess_led_pin: int        = 19    # BOARD 19 (SPI1 MOSI)
    chess_led_count: int      = 64
    chess_led_brightness: int = 76    # 0-255 — ~30% prevents micro-USB overcurrent
    chess_led_channel: int    = 0     # unused by adafruit_neopixel_spi
    panel_led_pin: int        = 33    # unused until panel hardware present
    panel_led_count: int      = 22
    panel_led_brightness: int = 0
    panel_led_channel: int    = 1
    led_freq_hz: int          = 800_000  # unused by adafruit_neopixel_spi
    led_dma: int              = 10       # unused by adafruit_neopixel_spi
    led_invert: bool          = False    # unused by adafruit_neopixel_spi

    # ── Button hardware ───────────────────────────────────────────────────────
    button_debounce_s: float  = 0.05
    hint_pin: int             = 11    # Col_2 pin (hint cell is Row_3 Col_2)
    button_pins: dict         = field(default_factory=lambda: {
        1: 11,    # Row_4 Col_2
        2: 7,     # Row_4 Col_1
        3: 11,    # Row_1 Col_2
        4: 7,     # Row_1 Col_1
        5: 11,    # Row_5 Col_2
        6: 7,     # Row_5 Col_1
        7: 11,    # Row_2 Col_2
        8: 7,     # Row_2 Col_1
        9: 7,     # Row_3 Col_1  (OK / confirm)
    })

    # ── OLED ──────────────────────────────────────────────────────────────────
    # DFRobot OLED on I2C Bus 7 — BOARD pin 3 (SDA) and pin 5 (SCL)
    oled_i2c_port: int = field(default_factory=lambda: int(os.environ.get("OLED_I2C_PORT", "7")))
    oled_i2c_addr: int = field(default_factory=lambda: int(os.environ.get("OLED_I2C_ADDR", "0x3C"), 16))
    oled_width: int    = 128
    oled_height: int   = 64

    # ── Web server ────────────────────────────────────────────────────────────
    web_host: str = "0.0.0.0"
    web_port: int = 5000
    dev_pin:  str = "1234"    # PIN for the dev menu on the dashboard

    # ── Gameplay ──────────────────────────────────────────────────────────────
    hint_dismiss_s: float    = 4.0   # seconds hint stays lit before auto-dismiss
    undo_max_half_moves: int = 10    # max half-moves the undo stack holds
    startup_led_delay_s: float = 0.015  # fast sweep — not the original 1 s per LED
    web_splash_hold_s: float   = 5.0    # how long to show splash before hiding
    menu_sleep_timeout_s: float = 60.0  # Inactivity seconds before menu sleep mode kicks in
    hint_dismiss_s: float    = 4.0   # seconds hint stays lit before auto-dismiss

    # ── Game save (USB) ───────────────────────────────────────────────────────
    usb_mount_paths: list = field(default_factory=lambda: [
        "/media", "/mnt", "/run/media"
    ])
    pgn_subdir: str = "chess_games"   # created inside the USB root

    # ── Voice announcements ───────────────────────────────────────────────────
    tts_rate: int    = 165   # words per minute for espeak-ng / pyttsx3
    tts_volume: float = 0.9  # 0.0 – 1.0


# Singleton used across the whole project
CFG = GameConfig()

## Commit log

2026-06-11 Added STL Files
    [Chessboard - Blank.STL, Chessboard - Bottom Elec Split.stl, Chessboard - Bottom Lights.STL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]
2026-06-12 fix: handle None score in Stockfish evaluation; refactor button GPIO setup and improve type hints
    [buttons.py, main.py, server.py]
2026-06-13 fix: update button pin mapping and improve button handling; refactor LED control for SPI compatibility
    [buttons.py, config.py, leds.py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]
2026-06-14 Add matrix button test script for GPIO input handling
    This commit introduces a new Python script that tests a matrix button setup using Jetson.GPIO. The script configures GPIO pins for two columns and five rows, allowing for button presses to be detecte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
2026-06-14 fix: update LED configuration comments and improve button sampling parameters; refactor LED controller for SPI compatibility
    [buttons.py, config.py, leds.py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]
2026-06-15 Refactor board state row conversion, update button debounce logic, and enhance OLED display for setup phases
    - Updated `row_from_char` method in `board_state.py` for clarity in rank conversion.
    - Added `web_splash_hold_s` configuration in `config.py` for splash screen duration.
    - Adjusted button debounce settings in `buttons.py` for improved responsiveness.
    - Modified LED square indexing logic in `leds.py` to ensure correct pixel mapping.
    - Changed initialization log message in `main.py` to reflect version 3.
    - Enhanced game setup logic in `main.py` to support live slider previews for difficulty and time settings.
    - Updated OLED display methods in `oled_display.py` to show time options in a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
    [buttons.py, config.py, leds.py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]
2026-06-15 Added 3D printed feet for board
    [Chessboard - Feet.stl]
2026-06-15 Refactor main.py for improved clarity and structure; remove test.py; enhance animations and display logic
    - Updated main.py to streamline code, improve logging, and enhance readability.
    - Removed test.py as it was deemed unnecessary for current testing needs.
    - Enhanced animations in animations.py to automatically restore board theme after thinking.
    - Refined display.py to align visual indicators with hardware orientation and improve clarity.
2026-06-15 refactor: clean up comments and remove obsolete code in configuration, display, and button handling files; delete unused test files
2026-06-15 refactor: enhance button driver with background polling and improve coordinate handling in main game loop; update OLED display for move input
2026-06-15 feat: Enhance theme customization and add OLED mirror functionality
    - Implement dynamic dark square color calculation for custom themes in AnimationEngine.
    - Introduce sleep animation with a breathing wave pattern for LEDs.
    - Add OLED text mirroring feature in the web server, allowing real-time updates to the OLED panel.
    - Update the web interface to include a live OLED screen mirror and improve theme designer layout.
    - Refactor theme application logic to ensure consistent color updates across the application.
2026-06-15 feat: Implement web confirmation handling to bypass physical button press for move inputs
2026-06-15 Add USB storage functionality for game saving and loading
    - Implemented USBStorage class for managing USB drives.
    - Added methods to save, load, list, delete, and import PGN files.
    - Created a script for auto-mounting USB drives on plug-in.
    - Added udev rules for USB hotplug detection.
    - Updated setup instructions for USB functionality.
    - Introduced logging for USB operations to aid in troubleshooting.
2026-06-15 fix: update button debounce time to improve input responsiveness
    [config.py]
